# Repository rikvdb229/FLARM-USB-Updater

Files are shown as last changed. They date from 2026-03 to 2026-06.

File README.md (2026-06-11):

# FLARM USB Updater — REV B

USB-to-RS232 adapter with 12V boost converter for updating FLARM firmware without external power.

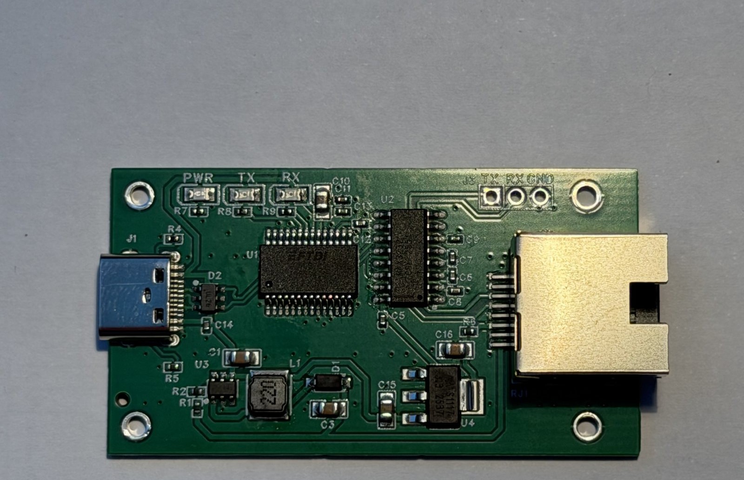
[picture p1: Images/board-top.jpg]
FLARM USB Updater REV B — assembled board


Plug into a PC USB port → connect RJ45 cable to FLARM → run firmware update tool. No 12V bench supply required. Also supports FLARM display firmware updates via the same connector.

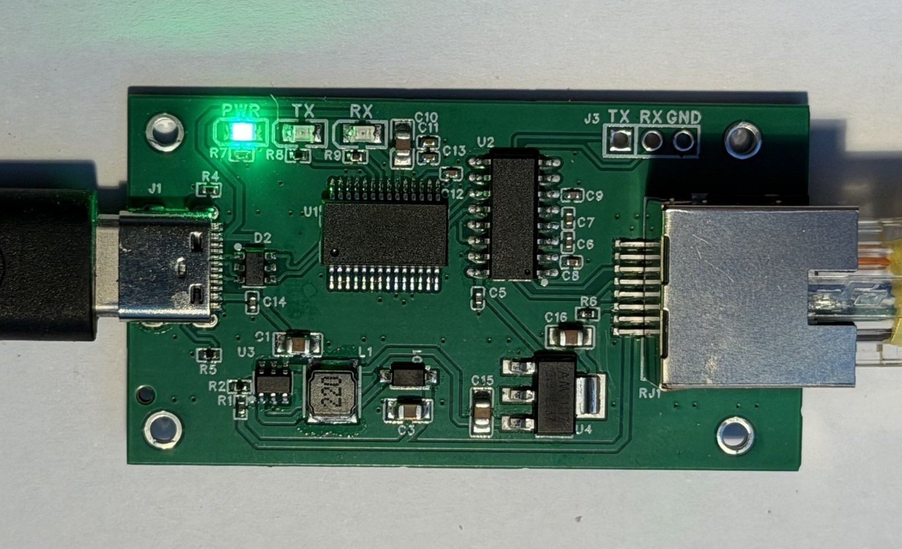
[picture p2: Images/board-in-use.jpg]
In use — USB-C from the PC, RJ45 to the FLARM, green PWR LED lit


> **Tip — connection order:** connect the RJ45 to the FLARM *before* plugging the adapter into the PC. If you hot-plug the FLARM while it's already on USB, the COM port may briefly disconnect and reappear — that's harmless inrush (charging the FLARM's input capacitors through the boost momentarily dips the USB 5 V rail and re-enumerates the FT232), not a fault.

> **Status:** REV B **built and validated** — bench-tested and confirmed updating real FLARM hardware over USB (boost, 12 V rail, and full serial path all verified). Fixes the REV A boost topology bug (12 V rail was dead on all REV A boards). See [Archive/REV_A/](Archive/REV_A/) for the REV A schematic, rework guide, and bring-up log.

> **Disclaimer:** This is an unofficial, community-built project. It is **not affiliated with, authorized, sponsored, or endorsed by FLARM Technology Ltd.** "FLARM" and "PowerFLARM" are trademarks of FLARM Technology Ltd.; they are used here only to describe device compatibility. Firmware updates are performed using FLARM's own official update tool — this project supplies power and a serial connection only. Use at your own risk; you are responsible for any device you connect it to.

> 🛒 **Want one ready-made?** Pre-built, tested boards for fellow pilots — **~€40, shipping excluded** (cost-share to fund the next batch). Start a [Discussion](../../discussions) or email [flarm@rvdb.dev](mailto:flarm@rvdb.dev).

## Features

- Powered entirely from USB (5V)
- 5V → ~12V boost converter (MT3608) supplies FLARM via RJ45 pins 1 & 2
- FT232RL USB-to-UART bridge — uses Microsoft built-in usbser.sys, no driver install on Win10/11
- MAX3232 RS232 level shifter, powered from the 3.3V rail (±5V signaling, RS232-compliant with all FLARM RS232 ports)
- B5819W Schottky boost freewheel diode — also provides backfeed protection into live 12V aircraft bus
- USB ESD protection (USBLC6-2SC6) on D+/D−
- USB-C connector with proper CC pull-downs
- Power, TX and RX LED indicators
- Dedicated AMS1117-3.3 LDO — 3.3V supply for FLARM accessories (RJ45 pin 3), up to 800mA
- R6 (10Ω) isolates AMS1117 output from FLARM's internal 3.3V on pin 3

## Hardware

Designed in **EasyEDA Pro** for direct JLCPCB SMT assembly ordering.

**PCB REV B:** 53.4 × 30.5 mm (2102 × 1200 mil), 2-layer FR4, 1oz copper. Single-sided top routing with a solid bottom GND plane, 54 stitching vias.

> **Note on C-numbers:** IC and connector C-numbers are confirmed. Passive C-numbers
> (resistors/caps) are from the JLCPCB Basic parts library and should be verified in
> EasyEDA before ordering — search the value + package if a number doesn't match.

### Component List (REV B)

| Ref  | Description | JLCPCB # | Class |
| ---- | --- | --- | --- |
| U1 | FT232RL USB-UART SSOP-28 | C8690 | Extended |
| U2 | MAX3232CSE+T RS232 transceiver SOIC-16 | C7258 | Extended |
| U3 | MT3608 boost converter SOT-23-6 | C84817 | Extended |
| U4 | AMS1117-3.3 LDO regulator SOT-223 | C6186 | Basic |
| L1 | 22µH shielded inductor 1A (SMNR4020) | C135264  | Extended |
| D1 | B5819W SL Schottky 40V/1A SOD-123 | C8598 | Basic |
| D2 | USBLC6-2SC6 USB ESD clamp SOT-23-6 | C7519 | Extended |
| J1 | USB-C receptacle TYPE-C-31-M-12 | C165948  | Extended |
| RJ1  | RJ45 SMD 8P8C (RJ-064-1) | C7205199 | Extended |
| J3 | 1×3 PTH header 2.54mm (unpopulated) | — | — |
| LED1 | Green LED 0805 — power (KT-0805G) | C2297 | Basic |
| LED2 | Yellow LED 0805 — TX (KT-0805Y) | C2296 | Basic |
| LED3 | Yellow LED 0805 — RX (KT-0805Y) | C2296 | Basic |
| R1 | 100kΩ 0402 — MT3608 FB top | C25741 | Basic |
| R2 | 5.1kΩ 0402 — MT3608 FB bottom | C25905 | Basic |
| R4 | 5.1kΩ 0402 — USB-C CC1 | C25905 | Basic |
| R5 | 5.1kΩ 0402 — USB-C CC2 | C25905 | Basic |
| R6 | 10Ω 0402 — RJ45 pin 3 isolation | C25077 | Basic |
| R7 | 680Ω 0402 — power LED | C25130 | Basic |
| R8 | 680Ω 0402 — TX LED | C25130 | Basic |
| R9 | 680Ω 0402 — RX LED | C25130 | Basic |
| C1 | 22µF / 25V 0805 — MT3608 Vin | C45783 | Basic |
| C3 | 22µF / 25V 0805 — MT3608 Vout | C45783 | Basic |
| C5 | 100nF 0402 — MAX3232 VCC bypass (3.3V rail)| C307331  | Basic |
| C6 | 100nF 0402 — MAX3232 C1+/C1− (charge pump) | C307331  | Basic |
| C7 | 100nF 0402 — MAX3232 C2+/C2− (charge pump) | C307331  | Basic |
| C8 | 100nF 0402 — MAX3232 V+ storage | C307331  | Basic |
| C9 | 100nF 0402 — MAX3232 V− storage | C307331  | Basic |
| C10  | 4.7µF / 25V 0805 — FT232RL VCC bulk | C1779 | Basic |
| C11  | 100nF 0402 — FT232RL VCC | C307331  | Basic |
| C12  | 100nF 0402 — FT232RL VCCIO | C307331  | Basic |
| C13  | 100nF 0402 — FT232RL VCC | C307331  | Basic |
| C14  | 100nF 0402 — USBLC6 VCC | C307331  | Basic |
| C15  | 22µF / 25V 0805 — AMS1117 Vin | C45783 | Basic |
| C16  | 22µF / 25V 0805 — AMS1117 Vout | C45783 | Basic |

**35 components (34 SMT + 1 PTH unpopulated) — 7 Extended parts ($21 JLCPCB setup fees)**

### Net Names

| Net | Description | Trace class |
| --- | --- | --- |
| VUSB | USB 5V power rail | Power (≥20mil) |
| GND | Ground (pour both layers) | pour |
| SW | MT3608 switching node (L1 → U3 SW → D1 anode) | default |
| V12_OUT | After Schottky D1 (~12.0V) to RJ45 pins 1,2 | Power_12V (≥15mil) |
| V3V3 | AMS1117-3.3 output | default |
| V3V3_OUT | After R6 to RJ45 pin 3 | default |
| FT_3V3 | FT232RL 3V3OUT (pin 17, decoupling only) | default |
| UART_TX | FT232RL TXD → MAX3232 T1IN → J3 | default |
| UART_RX | MAX3232 R1OUT → FT232RL RXD, also J3 | default |
| RS232_TX | MAX3232 T1OUT → RJ45 pin 6 | default |
| RS232_RX | RJ45 pin 5 → MAX3232 R1IN | default |
| UD+, UD− | USB data, FT232 side (diff pair DP1) | 6/6 mil |
| UD_IN+, UD_IN− | USB data, USB-C side (diff pair DP2) | 6/6 mil |
| CC1, CC2 | USB-C configuration channel | default |
| TXLED, RXLED | FT232RL CBUS0/CBUS1 (active-low) to LEDs | default |
| FB | MT3608 feedback node | default |
| CP1P, CP1N, CP2P, CP2N | MAX3232 charge pump | default |
| VS_POS, VS_NEG | MAX3232 V+/V− supply | default |
| LED1_K, LED2_K, LED3_K | LED cathode nodes | default |

### FLARM RJ45 Pinout (8P8C)

| Pin | Signal | This device |
| --- | --- | --- |
| 1, 2 | +12V | From boost via D1 (~12.0V) |
| 3 | FLARM 3V3 | From AMS1117-3.3 (U4) via R6 (10Ω) |
| 4, 7, 8 | GND | PCB GND |
| 5 | FLARM TX  | RS232 RX input (MAX3232 R1IN) |
| 6 | FLARM RX  | RS232 TX output (MAX3232 T1OUT) |
| 9, 10 | Shield | PCB GND copper pour |

The pinout is silkscreened on the back of the board:

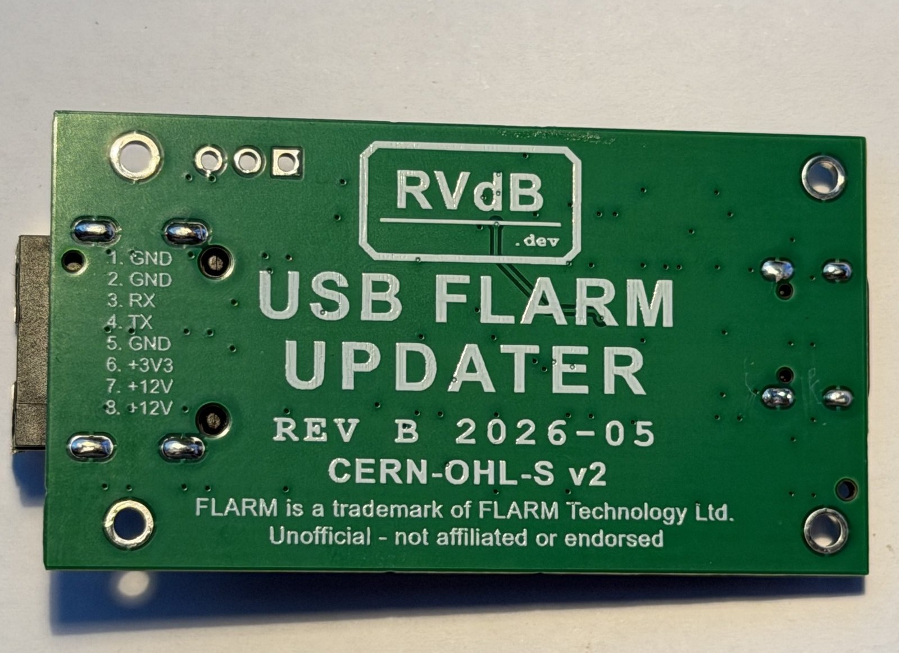
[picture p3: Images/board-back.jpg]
Board back — silkscreen pinout legend, branding, and CERN-OHL-S licence


> **SMD RJ45 note:** The RJ-064-1 connector uses reversed pad numbering (pad 1 = RJ45 pin 8). The PCB routing compensates for this — the netlist pad references and the RJ45 pin numbers in this table are intentionally different.

**Pin 3 design note:** FLARM outputs 3.3V on pin 3 (up to 200mA per FLARM manual) to power external accessories. The AMS1117-3.3 on this board also outputs 3.3V on pin 3. R6 (10Ω) isolates the two 3.3V sources:

- **FLARM update:** Both regulators output ~3.3V. R6 limits mismatch current to ~10mA max. AMS1117 handles this safely (no protection diode needed with small output caps).
- **Display update:** Display draws power from AMS1117 through R6. At 20mA → 0.2V drop (3.1V), at 50mA → 0.5V drop (2.8V). Most displays work fine at 3.0V+.
- **R6 can be replaced with 0Ω** if display voltage drop is an issue and FLARM backfeed isolation is not needed.

**Display updates — TX/RX crossover cable:** For display firmware updates, TX and RX
are swapped relative to FLARM updates. Use a crossover RJ45 cable (pins 5 and 6 swapped)
labeled "DISPLAY". RS232 is non-damaging if crossed — receivers are high-impedance.

### Breakout Header (unpopulated)

**J3 — TTL UART (1×3, 2.54mm)**

Exposes the TTL-level UART signals between the FT232RL and MAX3232. Not assembled by JLCPCB — solder a pin header when needed.

| Pin | Signal | Description |
| --- | --- | --- |
| 1 | TX | 3.3V TTL TX from FT232RL |
| 2 | RX | 3.3V TTL RX to FT232RL |
| 3 | GND | Signal reference |

> **VCCIO note:** The FT232RL VCCIO (pin 4) is tied to 3V3OUT (the FT232RL's internal 3.3V regulator), so J3 outputs **3.3V TTL** and is safe to connect directly to 3.3V MCUs (nRF, RP2040, ESP32, STM32, etc.). FT232RL VCC (pin 20) remains on USB 5V — that powers the USB interface and does not affect the I/O logic level. The MAX3232 is also powered from the 3.3V rail, so the FT232RL↔MAX3232 interface is level-matched on both directions with in-spec margin.

### LED Indicators

| LED  | Colour | Signal | Resistor | Current | Behaviour |
| ---- | --- | --- | --- | --- | --- |
| LED1 | Green (C2297)  | VUSB → R7 → GND | 680Ω | 3.2mA | Always on when USB connected |
| LED2 | Yellow (C2296) | VUSB → R8 → TXLED# | 680Ω | 4.3mA | Flashes during TX |
| LED3 | Yellow (C2296) | VUSB → R9 → RXLED# | 680Ω | 4.3mA | Flashes during RX |

TXLED# and RXLED# are active-low, default CBUS0/CBUS1 factory config — no EEPROM needed.

## What Else Can It Do?

With the FLARM cable connected, this board provides full RS232 + power — not just firmware updates:

- **IGC flight log download** — open FLARM Tool, download flight logs for OLC/competition submission.
- **FLARM configuration** — change aircraft type, competition ID, NMEA output sentences, baud rate, and other settings via the serial link.
- **Live NMEA diagnostics** — open a serial terminal (PuTTY, Tera Term) at 19200 baud to watch GPS, traffic, and error sentences in real-time.
- **General-purpose RS232 adapter** — make an RJ45 cable with only GND (pins 4/7/8), TX (pin 5), and RX (pin 6) connected. Leave pins 1/2 (12V) and 3 (3.3V) unconnected. The boost converter idles at ~1mA with no load.

## Cable Configurations

| Cable | Wiring | Use |
| --- | --- | --- |
| **FLARM** (straight) | All pins 1:1 | Firmware update, config, IGC download, diagnostics |
| **DISPLAY** (crossover) | Pins 5 ↔ 6 swapped | Display firmware update |
| **RS232 only** | Pins 4, 5, 6, 7, 8 only | General RS232 (no 12V/3.3V) |

## FT232RL EEPROM Customization (optional)

Use FTDI's free **FT_PROG** tool (Windows) to program the FT232RL's internal EEPROM:

- **Device description**: set to "FLARM USB Updater" — shows in Device Manager instead of generic "USB Serial Converter"
- **Serial number**: unique per board — helps identify the right COM port when multiple FTDI devices are connected

One-time USB programming step per board. Not required for basic operation.

## Boost Converter

Standard boost topology (fixed in REV B):

```
VUSB ── L1(22µH) ── SW ── D1 ── V12_OUT ── RJ45 pins 1,2
                    │
                   U3 SW pin
```

Vout = 0.6 × (1 + R1/R2) = 0.6 × (1 + 100k/5.1k) ≈ **12.35V**
After B5819W drop (~0.35V): ≈ **12.0V** at RJ45 — within FLARM 8–36V input range.

| Parameter | Value |
| --- | --- |
| Output voltage | 12.35V (12.0V after diode) |
| Duty cycle | ~60% |
| Inductor ripple | 113mA peak-to-peak |
| Peak inductor current | 304mA (vs 1A L1 rating) |
| Output ripple | <1mV estimated |
| Output cap | C3 = 22µF at 25V (2× voltage margin) |

## Power Budget

| Consumer | Current (mA) |
| --- | --- |
| FT232RL | 15 |
| MAX3232 | 5 |
| USBLC6 | 0.5 |
| AMS1117 quiescent | 5 |
| LED1 (power) | 3.2 |
| LED2 (TX, avg) | 2.2 |
| LED3 (RX, avg) | 2.2 |
| MT3608 boost @ 85mA load | 247 |
| **Total USB draw** | **~280mA** |

USB 2.0 limit: 500mA → 56% used. A **regular FLARM runs on any standard USB port** (bench-tested with a Flarm06).

A **PowerFLARM** draws more (~165mA @ 12V → ~510mA on USB) — fine on USB 3.0 / USB-C ports, which supply well above 500mA. On an older 500mA USB 2.0 port that's right at the limit, so if it doesn't power up, use a USB-C charger (1.5A+).

## Cost Estimate (JLCPCB SMT assembly)

| Qty | PCB | SMT | Extended fees | Components | Shipping | Total | Per board |
| --- | --- | --- | --- | --- | --- | --- | --- |
| 5 | $2  | $8  | $21 | ~$37.50 | ~$15 | ~$83.50 | ~$16.70 |
| 10  | $4  | $8  | $21 | ~$75 | ~$15 | ~$123 | ~$12.30 |

## Changes from REV A

REV A was ordered, received, and bench-tested. RS232, USB, 3.3V rail, and LEDs all worked. The 12V rail produced 0V on every board due to incorrect boost topology. Rework instructions are preserved in [Archive/REV_A/REV_A_Rework_Guide.md](Archive/REV_A/REV_A_Rework_Guide.md).

**Fixed in REV B:**

1. **Boost topology** — L1 moved from SW↔output to VUSB↔SW. D1 moved from output↔V12_OUT to SW↔V12_OUT. Now a standard boost.
2. **Removed R3** (10kΩ EN pull-up) — EN tied directly to VUSB.
3. **Removed C2** (100nF boost input HF) — not required by MT3608 datasheet.
4. **Removed C4** (4.7µF boost output aux) — not required by MT3608 datasheet.
5. **VBOOST net eliminated** — SW→D1→V12_OUT is one path.
6. **LED2 colour** — corrected from green to yellow (KT-0805Y / C2296) to match physical BOM.
7. **MAX3232 supply** — VCC (U2 pin 16) and its bypass cap C5 moved from VUSB (5V) to the 3.3V rail (AMS1117 V3V3, regulator side of R6). At VCC=3.3V the MAX3232 driver input threshold is 2.0V, which the FT232RL TXD (2.2V min at VCCIO=3.3V) meets in spec; previously the 5V-powered MAX3232 needed 2.4V and was out of spec worst-case. Both ICs now share the 3.3V rail (level-matched). J3 is therefore 3.3V TTL — safe for any 3.3V MCU.

## Design Verification (REV B)

Netlist + BOM review, re-verified 2026-05-15 against the REV B EasyEDA project export (programmatic netlist parse against component datasheets):

- FT232RL: all 28 pins verified (TEST→GND, CTS/DSR/DCD/RI→GND, OSCI/OSCO NC, VCC on VUSB=5V, VCCIO on FT_3V3=3.3V)
- MAX3232: VCC on V3V3 (3.3V rail); C5 VCC bypass; C6/C7 charge pump flying caps; C8/C9 V+/V− storage. Ch1 UART↔RS232. T2IN (pin 10) tied to GND.
- MT3608: VUSB→L1→SW→D1→V12_OUT. Feedback 100k/5.1k → 12.35V. **Boost topology correct (REV A bug fixed).**
- USB-C: CC1/CC2 pulldowns 5.1kΩ, D+/D− through USBLC6, diff-pair rule active (DP1, DP2, 6/6 mil), both orientations
- AMS1117-3.3: V3V3 → R6 (10Ω) → RJ45 pin 3, adequate headroom
- LED circuits: active-low CBUS, correct polarity, 3.2–4.3mA current
- RJ45 pinout: matches FLARM IGC specification (accounting for SMD connector pad reversal)
- GND copper pour on both layers, 54 stitching vias
- Power budget: ~280mA within USB 2.0 500mA limit
- All capacitor voltage ratings: ≥1.8×, all resistor power ratings: <40%

## Bring-up Checklist (before connecting to FLARM)

1. Visual inspection: USB-C orientation, RJ45 jack seating, no tombstoned 0402s
2. USB plug-in: LED1 (green) on. Host enumerates as FTDI serial device.
3. DMM: 5V on VUSB test points, 3.3V on V3V3, **12.0V on V12_OUT (RJ45 pins 1,2)**
4. Loopback test via `flarm_query.py` or `flarm_monitor.py` — TX/RX LEDs flash
5. Connect FLARM on bench supply first (not live 12V aircraft bus) for initial test

## Files

- [EDA/USB_FLARM_UPDATER.eprj](EDA/USB_FLARM_UPDATER.eprj) — EasyEDA Pro project (REV B)
- [EDA/ProPrj_USB_FLARM_UPDATER_2026-05-29.epro](EDA/ProPrj_USB_FLARM_UPDATER_2026-05-29.epro) — REV B as-built source export (the fabbed design)
- [EDA/Gerber_PCB1_2026-05-27.zip](EDA/Gerber_PCB1_2026-05-27.zip) — REV B Gerber for JLCPCB
- [EDA/BOM_Board1_PCB1_2026-05-27.csv](EDA/BOM_Board1_PCB1_2026-05-27.csv) — REV B BOM
- [EDA/PickAndPlace_PCB1_2026-05-27.xlsx](EDA/PickAndPlace_PCB1_2026-05-27.xlsx) — REV B SMT pick-and-place
- [EDA/Netlist_Schematic1_2026-05-27.tel](EDA/Netlist_Schematic1_2026-05-27.tel) — REV B netlist (for parser audit)
- [EDA/silkscreen_back_REV_B.svg](EDA/silkscreen_back_REV_B.svg) — back silkscreen artwork
- [EDA/USB_FLARM_UPDATER_backup/](EDA/USB_FLARM_UPDATER_backup/) — dated project snapshots
- [EDA/3DPCB.step](EDA/3DPCB.step) — board 3D model (STEP) for enclosure / mechanical design
- [Images/](Images/) — board photos used in this README
- [Docs/FLARM_USB_Updater_Design_Document.docx](Docs/FLARM_USB_Updater_Design_Document.docx) — design document (BOM, pinout, power budget, bring-up)
- Component datasheets — see each part's LCSC code (C-number) in the [BOM](EDA/BOM_Board1_PCB1_2026-05-27.csv); enter it at lcsc.com for the datasheet
- [Enclosure/](Enclosure/) — 3D-printable case: `box` + `lid` (STEP/3MF/STL) and `enclosure-assembly.step` (board-in-box fit reference)
- [Archive/REV_A/](Archive/REV_A/) — REV A schematic, PCB, BOM, Gerber, rework guide, bring-up log
- [flarm_query.py](flarm_query.py) — query a connected FLARM (version / device info); [flarm_monitor.py](flarm_monitor.py) — log the serial NMEA stream
- [LICENSE](LICENSE) — CERN-OHL-S v2 licence text

## Support the project

This is fully open hardware — anyone can build the board from the Gerbers in [EDA/](EDA/) and the BOM. If the design or documentation saved you time, or you'd like to back continued development:

- ☕ **[Buy Me a Coffee](https://buymeacoffee.com/rikvdb)** — one-time thanks, any amount
- 🛒 **Pre-built, tested boards** (~€40, shipping excluded) — see the note at the top, or reach out via [Discussions](../../discussions) / [flarm@rvdb.dev](mailto:flarm@rvdb.dev)

Buying a board doesn't get you anything the open files don't — you're paying for assembly, testing, and the time saved. The repo is the canonical source either way.

## Questions & Contact

- 🐛 **Bug or technical problem** → [open an issue](../../issues/new)
- 💬 **Question, build help, or interested in a board** → [GitHub Discussions](../../discussions)
- ✉️ **Private / direct** → [flarm@rvdb.dev](mailto:flarm@rvdb.dev)

## License

Copyright Rik Vanden Boer.

This source describes Open Hardware and is licensed under the **CERN-OHL-S v2** (CERN Open Hardware Licence Version 2 — Strongly Reciprocal). You may redistribute and modify this source and make products using it under the terms of CERN-OHL-S v2 ([LICENSE](LICENSE)).

This source is distributed WITHOUT ANY EXPRESS OR IMPLIED WARRANTY, INCLUDING OF MERCHANTABILITY, SATISFACTORY QUALITY AND FITNESS FOR A PARTICULAR PURPOSE. Please see the licence for the full text.

As a strongly reciprocal licence: if you make and distribute a (modified) board based on this design, you must make the complete source (schematics, PCB, BOM) available under the same licence.

"FLARM" and "PowerFLARM" are trademarks of FLARM Technology Ltd. and are **not** covered by this licence — see the disclaimer at the top of this document.

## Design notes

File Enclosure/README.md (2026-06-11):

# Enclosure

3D-printable case for the FLARM USB Updater (REV B).

## Files
Each part comes as `.step`/`.3mf` (editable source — open in FreeCAD, Fusion 360, etc.) and `.stl` (print-ready mesh).
- **`box.*`** — the case body.
- **`lid.*`** — **plain lid** (no markings). The default for builders.
- **`lid_branded.*`** — same lid with the **RVdB.dev / USB FLARM UPDATER** logo embossed on top. Print this if you want the branded look, or `lid.*` for a clean one.
- **`enclosure-assembly.step`** — board-in-box fit **reference only, do not
  print**. Shows how the REV B PCB sits inside the case (USB-C and RJ45 cutout
  alignment); use it if you respin the board or modify the case.

Both lids share the same outer geometry and fit the same box — they differ only in the top-face emboss.

> Slicers Bambu Studio / OrcaSlicer / PrusaSlicer also import the `.step`/`.3mf`
> directly, so you usually don't need the STL.

## Printing
- **Material:** PLA is fine for normal bench/hangar use — the board barely makes
  heat (~2.5 W max off USB). **Use PETG or ASA if a unit might be left in a hot
  cockpit or car** (PLA softens ~50–60 °C; a sun-baked cockpit exceeds that).
- **Suggested settings:** ~0.2 mm layers, 3 perimeters, 15–20 % infill. No
  supports needed if the connector openings face up; otherwise minimal supports
  at the USB-C / RJ45 cutouts.

## Fit
Designed around the REV B PCB outline with openings for the **USB-C (J1)** and
**RJ45 (RJ1)** connectors and a window for the LEDs. If you respin the board,
re-check the cutout positions against the new layout before printing.

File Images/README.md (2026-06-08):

# Images

Photos and screenshots used in the main README and for sharing the project.

Suggested files (drop them here with these names so README links stay stable):

| File | What | Use |
|---|---|---|
| `board-top.jpg` | assembled board, top-down, clean background | README hero shot + GitHub social preview |
| `board-in-use.jpg` | plugged into a laptop USB-C with RJ45 to a FLARM | shows the value prop ("no bench supply") |
| `board-back.jpg` | back silkscreen artwork (logo / licence / trademark) | shows the custom branding |
| `terminal-update.png` | serial terminal / FLARM update succeeding | proof of function (optional) |
| `enclosure.jpg` | the 3D-printed case (with board inside) | add after the print is done |

**Formats:** JPG for photos (smaller), PNG for screenshots. Keep each under
~1–2 MB so the repo stays lightweight.

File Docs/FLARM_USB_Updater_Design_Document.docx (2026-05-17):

# FLARM USB Updater

Hardware Design Document

REV B

PCB: 53.4 × 30.5 mm (2102 × 1200 mil), 2-layer FR4

April 2026

# 1. Overview

The FLARM USB Updater is a USB-to-RS232 adapter with an integrated 12V boost converter, designed to update FLARM firmware and FLARM displays without requiring external power. It connects to a PC via USB-C and to the FLARM unit via an RJ45 cable following the IGC specification.

## 1.1 Key Features

- USB-C powered — no external 12V supply needed
- FT232RL USB-UART bridge (uses built-in Windows usbser.sys driver)
- MAX3232 RS232 level converter for FLARM communication
- MT3608 boost converter: 5V USB → 12V FLARM power
- AMS1117-3.3 LDO for FLARM 3.3V pin
- USBLC6-2SC6 ESD protection on USB data lines
- 3 status LEDs: power (green), TX (green), RX (yellow)
- TTL UART breakout header (J3) for direct TTL access
- All SMT, JLCPCB assembly compatible

## 1.2 Use Cases

1. FLARM firmware updates (straight RJ45 cable)
2. FLARM display updates (crossover RJ45 cable, pins 5+6 swapped)
3. IGC flight log download
4. FLARM configuration and live NMEA diagnostics
5. General-purpose USB to RS232 adapter (cable with GND/TX/RX only)

# 2. System Architecture

The design consists of five functional blocks:

## 2.1 Power Supply

Boost Converter (MT3608): Standard boost topology. L1 (22µH) sits between VUSB and SW node. MT3608 internal FET switches SW to GND; Schottky D1 (B5819W) conducts when FET opens, storing L1's magnetic energy into C3. Feedback divider R1 (100kΩ) / R2 (5.1kΩ) sets Vout = 0.6 × (1 + R1/R2) ≈ 12.35V, yielding ~12.0V at RJ45 after the ~0.35V D1 drop. 22µH is the top of the MT3608 recommended range, chosen for lower peak current and output ripple at the ~85mA FLARM load.

LDO (AMS1117-3.3): Provides 3.3V from USB 5V for FLARM pin 3. R6 (10Ω) limits current between the LDO output and FLARM's internal 3.3V regulator to prevent backfeed.

Power Budget: Classic FLARM draws ~85mA at 12V. Total USB current: ~280mA, well within any USB port's capability.

## 2.2 USB Interface

USB-C connector (J1) with CC1/CC2 pull-down resistors (R4, R5: 5.1kΩ) for UFP sink identification. USBLC6-2SC6 (D2) provides ESD protection on D+/D- lines. Both USB-C orientations are supported.

## 2.3 USB-UART Bridge

FT232RL (U1) converts USB to TTL UART. Chosen over CH340C because the November 2024 Windows Update broke CH340 drivers; FT232RL uses the built-in usbser.sys driver. CBUS0 (TXLED#) and CBUS1 (RXLED#) drive status LEDs via active-low outputs. Pin 26 (TEST) tied to GND. Unused modem control inputs (RI#, DSR#, DCD#, CTS#) tied to GND.

## 2.4 RS232 Level Converter

MAX3232 (U2) converts TTL UART to RS232 levels. U2 is powered from the 3.3V rail (V3V3, AMS1117 output on the regulator side of R6), so the FT232RL↔MAX3232 interface is level-matched at 3.3V in both directions with in-spec margin (MAX3232 driver V_IH = 2.0V at VCC = 3.3V; FT232RL TXD high = 2.2V min at VCCIO = 3.3V). C5 is VCC bypass (pin 16). C6/C7 are the charge pump flying caps (C1±/C2±). C8/C9 are V+/V- storage caps. All five are 100nF, which is the MAX3232 datasheet value for 3V–5.5V operation. Channel 1 carries FLARM communication. Channel 2 is unused; T2IN (pin 10) is tied to GND to prevent floating-input oscillation; the other channel-2 pins are left floating (allowed by datasheet).

## 2.5 LED Indicators

All LEDs use the same topology: VUSB → LED anode (pin 1) → LED cathode (pin 2) → R → sink.

- LED1 (green, KT-0805G): Power indicator. R7 (680Ω) to GND. Always on. I = (5-2.8)/680 = 3.2mA.
- LED2 (yellow, KT-0805Y): TX activity. R8 (680Ω) to TXLED (CBUS0). I = (5-2.1)/680 = 4.3mA when active.
- LED3 (yellow, KT-0805Y): RX activity. R9 (680Ω) to RXLED (CBUS1). I = (5-2.1)/680 = 4.3mA when active.

# 3. RJ45 Pinout (IGC Specification)

Pin numbering follows the IGC GNSS FR specification. The SMD RJ45 connector (RJ-064-1) has reversed pad numbering (pad 1 = RJ45 pin 8), accounted for in the PCB routing.

Pin | Signal | Notes
1 | +12V (V12_OUT) | Linked with pin 2
2 | +12V (V12_OUT) | Linked with pin 1
3 | +3.3V (V3V3_OUT via R6) | FLARM supplies 3V during updates
4 | GND | Linked with pins 7, 8
5 | FLARM TX (RS232_RX) | PC-side: SUB-D9 pin 2
6 | FLARM RX (RS232_TX) | PC-side: SUB-D9 pin 3
7 | GND | Linked with pins 4, 8
8 | GND | PC-side: SUB-D9 pin 5

# 4. Net Names

Net Name | Description
VUSB | USB 5V supply from USB-C
GND | Ground (pour both layers)
SW | Boost switch node (L1 → U3 SW → D1 anode)
V12_OUT | Boost output after Schottky D1 (~12.0V)
FB | Boost feedback divider midpoint (0.6V ref)
V3V3 | AMS1117 3.3V output
V3V3_OUT | 3.3V to FLARM via R6 (10Ω)
FT_3V3 | FT232RL 3V3OUT (pin 17, C12 decoupling only)
UD+ | USB data positive (differential pair, post-ESD)
UD- | USB data negative (differential pair, post-ESD)
UD_IN+ | USB data positive (USB-C side of USBLC6)
UD_IN- | USB data negative (USB-C side of USBLC6)
CC1 | USB-C configuration channel 1 (5.1kΩ to GND)
CC2 | USB-C configuration channel 2 (5.1kΩ to GND)
UART_TX | TTL-level TX (FT232RL → MAX3232 / J3)
UART_RX | TTL-level RX (MAX3232 / J3 → FT232RL)
RS232_TX | RS232-level TX (to FLARM RX on RJ45)
RS232_RX | RS232-level RX (from FLARM TX on RJ45)
TXLED | FT232RL CBUS0 (active-low TX indicator)
RXLED | FT232RL CBUS1 (active-low RX indicator)
CP1P/CP1N | MAX3232 charge pump 1 flying cap (C6)
CP2P/CP2N | MAX3232 charge pump 2 flying cap (C7)
VS_POS/VS_NEG | MAX3232 ± supply (C8/C9)
LED1_K/LED2_K/LED3_K | LED cathode nodes

# 5. Bill of Materials

34 SMT components + 1 PTH (J3 unpopulated). 7 Extended parts (× $3 = $21 setup fee). REV B removed R3 (EN pull-up — EN tied directly to VUSB), C2 (boost input HF), and C4 (boost output aux) — none required by the MT3608 datasheet.

Estimated cost: 5 boards ≈ $16.70/ea, 10 boards ≈ $12.30/ea

Ref | Part | Description | Package | LCSC | Class
U1 | FT232RL-REEL | USB to UART converter | SSOP-28 | C8690 | Extended
U2 | MAX3232CSE+T | RS232 transceiver (dual) | SOIC-16 | C7258 | Extended
U3 | MT3608 | Step-up DC-DC converter | SOT-23-6 | C84817 | Extended
U4 | AMS1117-3.3 | 3.3V LDO regulator | SOT-223 | C6186 | Basic
D1 | B5819W SL | Schottky diode (boost freewheel) | SOD-123 | C8598 | Basic
D2 | USBLC6-2SC6 | USB ESD protection | SOT-23-6 | C7519 | Extended
L1 | SMNR4020-22UH | 22µH inductor (boost) | 4x4mm SMD | C135264 | Extended
J1 | TYPE-C-31-M-12 | USB-C receptacle | SMD 12-pin | C165948 | Extended
RJ1 | RJ-064-1 | RJ45 jack (SMD) | SMD | C7205199 | Extended
J3 | HDR-M 1x3P | TTL UART breakout (unpop.) | 2.54mm PTH | N/A | N/A
LED1 | KT-0805G | Power LED (green) | 0805 | C2297 | Basic
LED2 | KT-0805Y | TX LED (yellow) | 0805 | C2296 | Basic
LED3 | KT-0805Y | RX LED (yellow) | 0805 | C2296 | Basic
R1 | 0402WGF1003TCE | 100kΩ ±1% (boost FB top) | 0402 | C25741 | Basic
R2 | 0402WGF5101TCE | 5.1kΩ ±1% (boost FB bottom) | 0402 | C25905 | Basic
R4 | 0402WGF5101TCE | 5.1kΩ ±1% (USB CC1) | 0402 | C25905 | Basic
R5 | 0402WGF5101TCE | 5.1kΩ ±1% (USB CC2) | 0402 | C25905 | Basic
R6 | 0402WGF100JTCE | 10Ω ±1% (LDO to RJ45) | 0402 | C25077 | Basic
R7 | 0402WGF6800TCE | 680Ω ±1% (power LED) | 0402 | C25130 | Basic
R8 | 0402WGF6800TCE | 680Ω ±1% (TX LED) | 0402 | C25130 | Basic
R9 | 0402WGF6800TCE | 680Ω ±1% (RX LED) | 0402 | C25130 | Basic
C1 | CL21A226MAQNNNE | 22µF 25V (boost input) | 0805 | C45783 | Basic
C3 | CL21A226MAQNNNE | 22µF 25V (boost output) | 0805 | C45783 | Basic
C5 | CL05B104KB54PNC | 100nF (MAX3232 VCC decoupling) | 0402 | C307331 | Basic
C6-C9 | CL05B104KB54PNC | 100nF (MAX3232 charge pump + V+/V-) | 0402 | C307331 | Basic
C10 | CL21A475KAQNNNE | 4.7µF (FT232RL VCC bulk) | 0805 | C1779 | Basic
C11-C13 | CL05B104KB54PNC | 100nF (FT232RL VCC/VCCIO decoupling) | 0402 | C307331 | Basic
C14 | CL05B104KB54PNC | 100nF (USBLC6 VCC) | 0402 | C307331 | Basic
C15 | CL21A226MAQNNNE | 22µF 25V (LDO input) | 0805 | C45783 | Basic
C16 | CL21A226MAQNNNE | 22µF 25V (LDO output) | 0805 | C45783 | Basic

# 6. PCB Design

Board: 53.4 × 30.5 mm (2102 × 1200 mil), 2-layer FR4, 1oz copper.

- GND copper pour on both layers; top pour fills gaps between traces, bottom is a solid GND plane
- All signal routing on top layer (single-sided routed) — bottom reserved for uninterrupted GND return
- 54 vias for GND stitching and bottom-plane pad connections
- Net class rules: Power (VUSB) ≥ 20mil, Power_12V (V12_OUT) ≥ 15mil
- USB differential pair (UD+/UD-, UD_IN+/UD_IN-): 6mil/6mil width/space, diff-pair rule active
- Designed in EasyEDA Pro, assembled by JLCPCB

# 7. Key Design Decisions

### FT232RL over CH340C

November 2024 Windows Update broke CH340 drivers. FT232RL uses the built-in usbser.sys driver, eliminating driver issues.

### USBLC6-2SC6 ESD Protection

Aviation and workshop environments have significant ESD risk. The USBLC6-2SC6 protects USB data lines with minimal capacitance impact.

### 22µH Inductor

Top of the MT3608 recommended range (4.7-22µH). Chosen for lower peak inductor current and reduced output ripple at our light load (~85mA at 12V). The SMNR4020-22UH (4x4mm) fits the board.

### R6 Current Limiter (10Ω)

FLARM outputs up to 200mA at 3.3V on pin 3 (per FLARM manual). Without R6, two LDO outputs would fight, causing uncontrolled current flow. R6 limits mismatch current to ~10mA max. AMS1117 handles backfeed safely with 22µF caps (no protection diode needed). Can be replaced with 0Ω if display voltage drop is an issue.

### 680Ω LED Resistors

KT-0805G (green) has a maximum forward current of 5mA. With 680Ω: I = (5-2.8)/680 = 3.2mA, providing comfortable margin. Yellow LEDs run at 4.3mA. Both values produce adequate brightness (430mcd green, 175mcd yellow).

# 8. Changes from REV A

REV A was ordered, received, and bench-tested. RS232, USB, 3.3V rail, and LEDs all worked. The 12V boost rail produced 0V due to incorrect L1/D1 placement. REV B fixes this and refines the MAX3232 supply; there are no deferred electrical issues.

### Fixed in REV B

- Boost topology corrected — L1 now between VUSB and SW (was between SW and output); D1 now between SW and V12_OUT (was between boost output and V12_OUT). Standard textbook boost.
- Removed R3 (10kΩ EN pull-up) — MT3608 EN tied directly to VUSB.
- Removed C2 (100nF boost input HF) — not required by datasheet; C1 (22µF) suffices.
- Removed C4 (4.7µF boost output aux) — not required by datasheet; C3 (22µF) suffices.
- VBOOST net eliminated — SW → D1 → V12_OUT is one continuous output path.
- LED2 colour corrected in documentation: KT-0805Y (yellow), matches physical BOM.
- MAX3232 supply — VCC (U2 pin 16) and bypass cap C5 moved from VUSB (5V) to the 3.3V rail (V3V3, AMS1117 output on the regulator side of R6). Closes a worst-case out-of-spec logic-high margin: a 5V-powered MAX3232 needs 2.4V V_IH but the FT232RL TXD only guarantees 2.2V at VCCIO=3.3V. At VCC=3.3V the MAX3232 V_IH is 2.0V — in spec. Both ICs now share the 3.3V rail.

### FT232RL VCCIO / J3 logic level

FT232RL VCCIO (pin 4) is tied to 3V3OUT (pin 17, the FT232RL's internal 3.3V regulator), so the J3 breakout header is 3.3V TTL — safe to connect directly to any 3.3V MCU (nRF, RP2040, ESP32, STM32). FT232RL VCC (pin 20) is on USB 5V, which powers the USB interface only and does not set the I/O logic level. There are no deferred electrical issues.

# 9. Design Verification (REV B)

Netlist and BOM review, re-verified 2026-05-15 against the REV B EasyEDA project export (programmatic netlist parse cross-checked against component datasheets):

- FT232RL: all 28 pins verified (TEST→GND, CTS/DSR/DCD/RI→GND, OSCI/OSCO NC, VCC on VUSB=5V, VCCIO on FT_3V3=3.3V)
- MAX3232: VCC on V3V3 (3.3V rail); C5 is VCC bypass; C6/C7 charge pumps; C8/C9 V± storage. Ch1 UART↔RS232, T2IN (pin 10) tied to GND
- MT3608: VUSB→L1→SW→D1→V12_OUT. Feedback 100k/5.1k gives 12.35V. Boost topology now correct
- USB-C: CC1/CC2 pulldowns 5.1kΩ, D+/D- through USBLC6 (diff-pair rule active), both orientations
- AMS1117: V3V3 → R6 (10Ω) → RJ45 pin 3, adequate headroom (1.7V)
- LED circuits: active-low CBUS, correct polarity, 3.2–4.3mA (LED2 now correctly yellow)
- RJ45 pinout matches FLARM IGC specification (SMD connector uses reversed pad numbering, compensated in routing)
- USB D+/D- configured as differential pair (DP1, DP2), 6mil/6mil
- GND pour both layers, 54 stitching vias
- Power budget: ~280mA within USB 2.0 500mA limit
- All capacitor voltage ratings ≥1.8×, all resistor power ratings <40%

# 10. Status & Next Steps

1. REV B fabrication files exported (Gerber, BOM, Pick-and-Place) — ready for JLCPCB order
2. Bring-up plan: verify 12V at RJ45 pins 1/2 with DMM before connecting FLARM
3. Validate USB enumeration, TX/RX loopback via monitor_com11.py / poke_flarm.py
4. Program FT232RL EEPROM via FT_PROG (device description, unique serial) — optional

FLARM USB Updater — Design Document

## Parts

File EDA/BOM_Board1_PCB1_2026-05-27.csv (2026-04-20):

No. | Quantity | Comment | Designator | Footprint | Value | Manufacturer Part | Manufacturer | Supplier Part | Supplier
1 | 4 | 22uF | C1,C3,C15,C16 | C0805 | 22uF | CL21A226MAQNNNE | SAMSUNG(三星) | C45783 | LCSC
2 | 9 | 100nF | C5,C6,C7,C8,C9,C11,C12,C13,C14 | C0402 | 100nF | CL05B104KB54PNC | SAMSUNG(三星) | C307331 | LCSC
3 | 1 | 4.7uF | C10 | C0805 | 4.7uF | CL21A475KAQNNNE | SAMSUNG(三星) | C1779 | LCSC
4 | 1 | B5819W SL | D1 | SOD-123_L2.7-W1.6-LS3.7-RD-1 |  | B5819W SL | CJ(江苏长电/长晶) | C8598 | LCSC
5 | 1 | USBLC6-2SC6 | D2 | SOT-23-6_L2.9-W1.6-P0.95-LS2.8-BL |  | USBLC6-2SC6 | ST(意法半导体) | C7519 | LCSC
6 | 1 | TYPE-C-31-M-12 | J1 | USB-C_SMD-TYPE-C-31-M-12_1 |  | TYPE-C-31-M-12 | 韩国韩荣 | C165948 | LCSC
7 | 1 | HDR-M_2.54_1x3P | J3 | HDR-TH_3P-P2.54-V-M
8 | 1 | 22uH | L1 | IND-SMD_L4.0-W4.0_LQH44PN2R2MP0L | 22uH | SMNR4020-22UH | SXN(顺翔诺) | C135264 | LCSC
9 | 1 | KT-0805G | LED1 | LED0805-R-RD |  | KT-0805G | KENTO | C2297 | LCSC
10 | 2 | KT-0805Y | LED2,LED3 | LED0805-R-RD |  | KT-0805Y | KENTO | C2296 | LCSC
11 | 1 | 100kΩ | R1 | R0402 | 100kΩ | 0402WGF1003TCE | UNI-ROYAL(厚声) | C25741 | LCSC
12 | 3 | 5.1kΩ | R2,R4,R5 | R0402 | 5.1kΩ | 0402WGF5101TCE | UNI-ROYAL(厚声) | C25905 | LCSC
13 | 1 | 10Ω | R6 | R0402 | 10Ω | 0402WGF100JTCE | UNI-ROYAL(厚声) | C25077 | LCSC
14 | 3 | 680Ω | R7,R8,R9 | R0402 | 680Ω | 0402WGF6800TCE | UNI-ROYAL(厚声) | C25130 | LCSC
15 | 1 | RJ-064-1 | RJ1 | CONN-SMD_RJ-064 |  | RJ-064-1 | FG(富港) | C7205199 | LCSC
16 | 1 | FT232RL-REEL | U1 | SSOP-28_L10.2-W5.3-P0.65-LS7.8-BL |  | FT232RL-REEL | FTDI(飞特帝亚) | C8690 | LCSC
17 | 1 | MAX3232CSE+T | U2 | SOIC-16_L9.9-W3.9-P1.27-LS6.0-BL |  | MAX3232CSE+T | ADI(亚德诺)/MAXIM(美信) | C7258 | LCSC
18 | 1 | MT3608 | U3 | SOT-23-6_L2.9-W1.6-P0.95-LS2.8-BL |  | MT3608 | 西安航天民芯 | C84817 | LCSC
19 | 1 | AMS1117-3.3 | U4 | SOT-223-3_L6.5-W3.4-P2.30-LS7.0-BR |  | AMS1117-3.3 | AMS | C6186 | LCSC

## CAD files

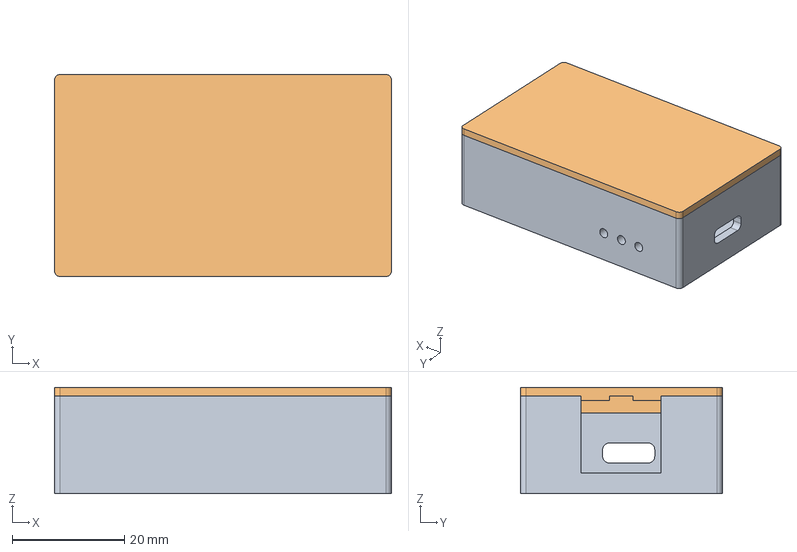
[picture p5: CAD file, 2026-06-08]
Enclosure/enclosure-assembly.step
60.0 x 36.0 x 19.0 mm
Box for PCB

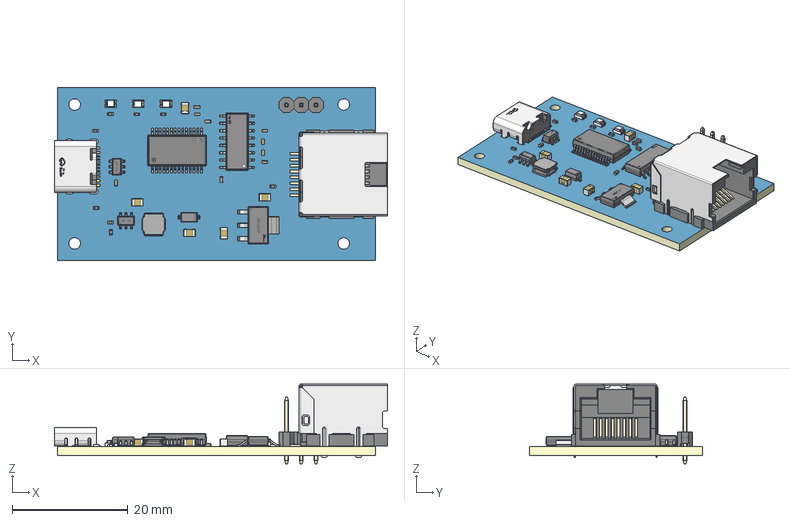
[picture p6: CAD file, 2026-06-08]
EDA/3DPCB.step
57.5 x 30.0 x 13.7 mm
Board~iIuz
TopCopper~iIuz
BottomCopper~iIuz
TopFpcStiffener~iIuz
BottomFpcStiffener~iIuz
C0402~C0402_L1.0-W0.5-H0.5~iIuz x 9
R0402~R0402_L1.0-W0.5-H0.4~iIuz x 8
SSOP-28_L10.2-W5.3-P0.65-LS7.8-BL~SSOP-28_ L10.2-W5.3-H2.0-LS7.8-P0.65~iIuz
LED0805-R-RD~LED0805-RD~iIuz x 3
HDR-TH_3P-P2.54-V-M~HDR-TH_3P-P2.54-M-LI-1X3P~iIuz
SOT-223-3_L6.5-W3.4-P2.30-LS7.0-BR~SOT-223-4P_ L6.5-W3.5-H1.6-LS7.0-P2.30~iIuz
SOT-23-6_L2.9-W1.6-P0.95-LS2.8-BL~SOT-23-6_ L2.9-W1.6-H1.5-LS2.8-P0.95~iIuz x 2
SOIC-16_L9.9-W3.9-P1.27-LS6.0-BL~SOIC-16_ L9.9-W3.9-H1.8-LS6.0-P1.27~iIuz
USB-C_SMD-TYPE-C-31-M-12_1~USB-C_SMD-TYPE-C-31-M-12_1~iIuz
SOD-123_L2.7-W1.6-LS3.7-RD-1~SOD-123_L2.7-W1.6-LS3.7-RD-1~iIuz
IND-SMD_L4.0-W4.0_LQH44PN2R2MP0L~IND-SMD_L4.0-W4.0-H1.65~iIuz
C0805~C0805_L2.0-W1.3-H1.3~iIuz x 5
CONN-SMD_RJ-064~RJ45-SMD_RJ-064~iIuz

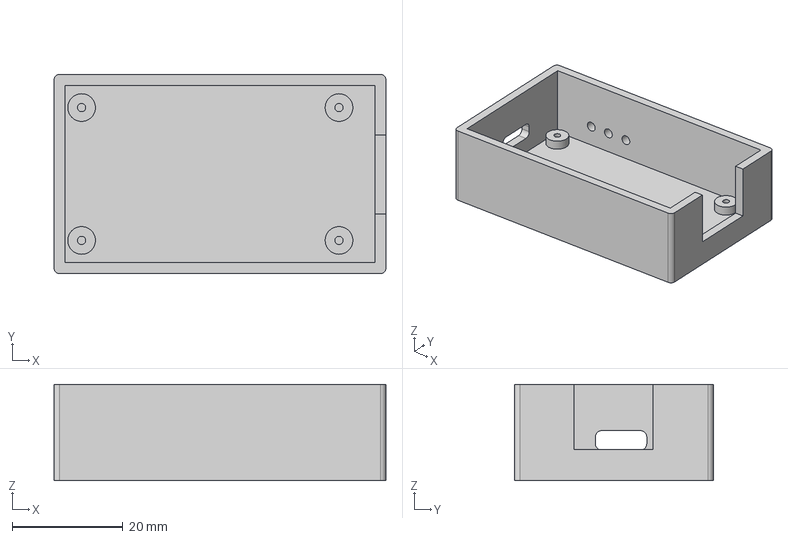
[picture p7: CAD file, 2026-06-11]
Enclosure/box.step
60.0 x 36.0 x 17.4 mm

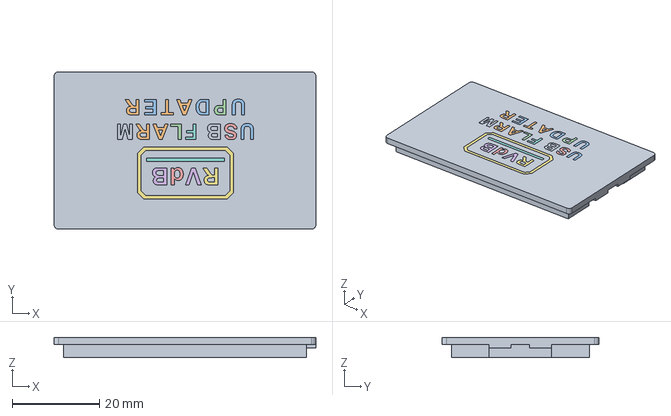
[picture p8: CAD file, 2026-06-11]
Enclosure/lid_branded.step
60.0 x 36.0 x 4.60 mm

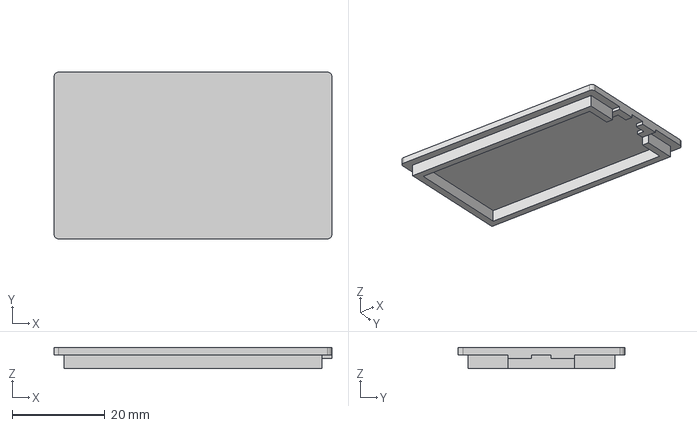
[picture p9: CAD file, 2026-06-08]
Enclosure/lid.step
60.0 x 36.0 x 4.60 mm

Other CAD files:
Enclosure/box.3mf
Enclosure/box.stl
Enclosure/lid.3mf
Enclosure/lid.stl
Enclosure/lid_branded.3mf
Enclosure/lid_branded.stl

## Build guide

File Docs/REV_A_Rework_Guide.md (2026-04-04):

# REV A Rework Guide — Boost Converter Fix

**Board:** FLARM USB Updater REV A
**Issue:** MT3608 boost converter produces 0V — L1 and D1 are in the wrong position
**Fix:** Desolder L1 and D1, resolder with correct topology

## Bug

The inductor (L1) is between SW and VBOOST. It must be between VUSB and SW.
The diode (D1) is between VBOOST and V12_OUT. It must be between SW and VBOOST.

**Before (wrong):**
```
VUSB ── IN    SW ── L1 ── VBOOST ── D1 ── V12_OUT
```

**After (correct):**
```
VUSB ── L1 ── SW ── D1 ── V12_OUT
                             │
                        C3, C4, R1/R2
```

## Tools needed

- Soldering iron with fine tip
- Hot air station (or second iron for D1)
- Flux
- 30 AWG wire or thin enameled wire
- Tweezers
- Kapton tape
- Multimeter
- Solder wick or desoldering braid

## Components involved

| Ref | Part | Package | Notes |
|-----|---|---|---|
| L1 | SMNR4020 22µH | 4.0 x 4.0 mm | Non-polarized, either orientation |
| D1 | B5819W SL | SOD-123 | Anode = unmarked end, Cathode = bar marking |

## Rework steps

### Step 1 — Desolder L1

1. Apply flux around L1 (4x4mm shielded inductor)
2. Heat with hot air at ~350°C or use iron on both pads alternately
3. Lift L1 off with tweezers
4. Clean pads with solder wick
5. Set L1 aside — it will be reused

### Step 2 — Desolder D1

1. Apply flux around D1 (SOD-123, near L1)
2. Heat with hot air or use two irons on both pads simultaneously
3. Lift D1 off with tweezers
4. Clean pads with solder wick
5. Set D1 aside — it will be reused

### Step 3 — Bridge D1's empty pads

Solder a short wire or solder blob across D1's two empty pads. This connects
V12_OUT directly to the VBOOST net (C3, C4, R1 feedback divider), which is the
output of the boost converter.

**Verify with multimeter:** continuity between V12_OUT (RJ45 pins 1&2) and
C3 positive pad.

### Step 4 — Solder L1 with flying wires

1. Cut two pieces of 30 AWG wire, ~15mm each
2. Solder one wire to each pad of L1 (either orientation — inductor is non-polarized)
3. Solder wire A to **VUSB**: use C1 positive pad (22µF cap near MT3608 IN pin)
4. Solder wire B to **MT3608 pin 1 (SW)**: top-left corner pin of U3 (SOT-23-6)

**Verify with multimeter:**
- Continuity from L1 wire A to USB-C VBUS (pin A4/B4)
- Continuity from L1 wire B to MT3608 pin 1 only (no short to other pins)

### Step 5 — Solder D1 with flying wires

1. Cut two pieces of 30 AWG wire, ~15mm each
2. Identify D1 polarity: cathode has a **bar marking** on the package
3. Solder one wire to each end of D1
4. Solder **anode** wire to **MT3608 pin 1 (SW)** — same point as L1 wire B
5. Solder **cathode** wire to **VBOOST/V12_OUT**: use C3 positive pad

**Verify with multimeter (diode mode):**
- Red probe on SW (MT3608 pin 1), black probe on C3 positive → should read ~0.2–0.4V (forward drop)
- Reverse probes → should read OL (open)

### Step 6 — Secure flying components

1. Tack L1 and D1 to the board with a small piece of Kapton tape
2. Ensure no wire-to-wire shorts between L1 and D1 leads
3. Route wires so they don't cross or touch other components

## Pre-power verification checklist

Run these multimeter checks BEFORE plugging in USB:

- [ ] No short between VUSB and GND
- [ ] No short between V12_OUT and GND
- [ ] Continuity: L1 wire A → VUSB rail
- [ ] Continuity: L1 wire B → MT3608 pin 1
- [ ] Continuity: D1 cathode → C3 positive / V12_OUT
- [ ] Continuity: D1 anode → MT3608 pin 1
- [ ] Diode check: SW → V12_OUT reads 0.2–0.4V forward
- [ ] D1 empty pads bridged: V12_OUT → C3 positive continuity
- [ ] No solder bridges on MT3608 (check all 6 pins)

## Power-on test

1. Plug in USB-C cable to a USB port (not a charger)
2. LED1 (green, power) should light up
3. Measure V12_OUT at RJ45 pins 1&2 relative to GND (pins 4/7/8)
4. **Expected: ~12.4V** (no diode drop — feedback regulates the output directly)
5. If voltage is correct, connect to FLARM and test firmware update

## Troubleshooting

| Symptom | Check |
|---|---|
| 0V on V12_OUT | D1 bridged pads? L1 connected to VUSB? |
| ~5V on V12_OUT | D1 reversed (anode/cathode swapped) |
| ~5V and getting hot | Solder bridge on MT3608 pins |
| Unstable / oscillating | Cold solder joint on L1 or D1 wires |
| USB port shuts down | Short between VUSB and GND — check all joints |

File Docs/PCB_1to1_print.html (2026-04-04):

# FLARM USB Updater — REV A — 1 : 1

Board outline at actual size (53.4 x 30.5 mm)

30.5 mm

FLARM USB
Updater
53.4 x 30.5 mm

53.4 mm

Scale check — this bar should measure exactly 100 mm with a ruler:

Each segment = 10 mm. If it doesn't match, adjust your printer to "Actual size" / 100% (not "Fit to page").

To print the full PCB layout at 1:1: Open Docs/PCB.pdf in your PDF viewer and print at 100% / Actual size. Use this page to verify your printer scale is correct with the ruler above.

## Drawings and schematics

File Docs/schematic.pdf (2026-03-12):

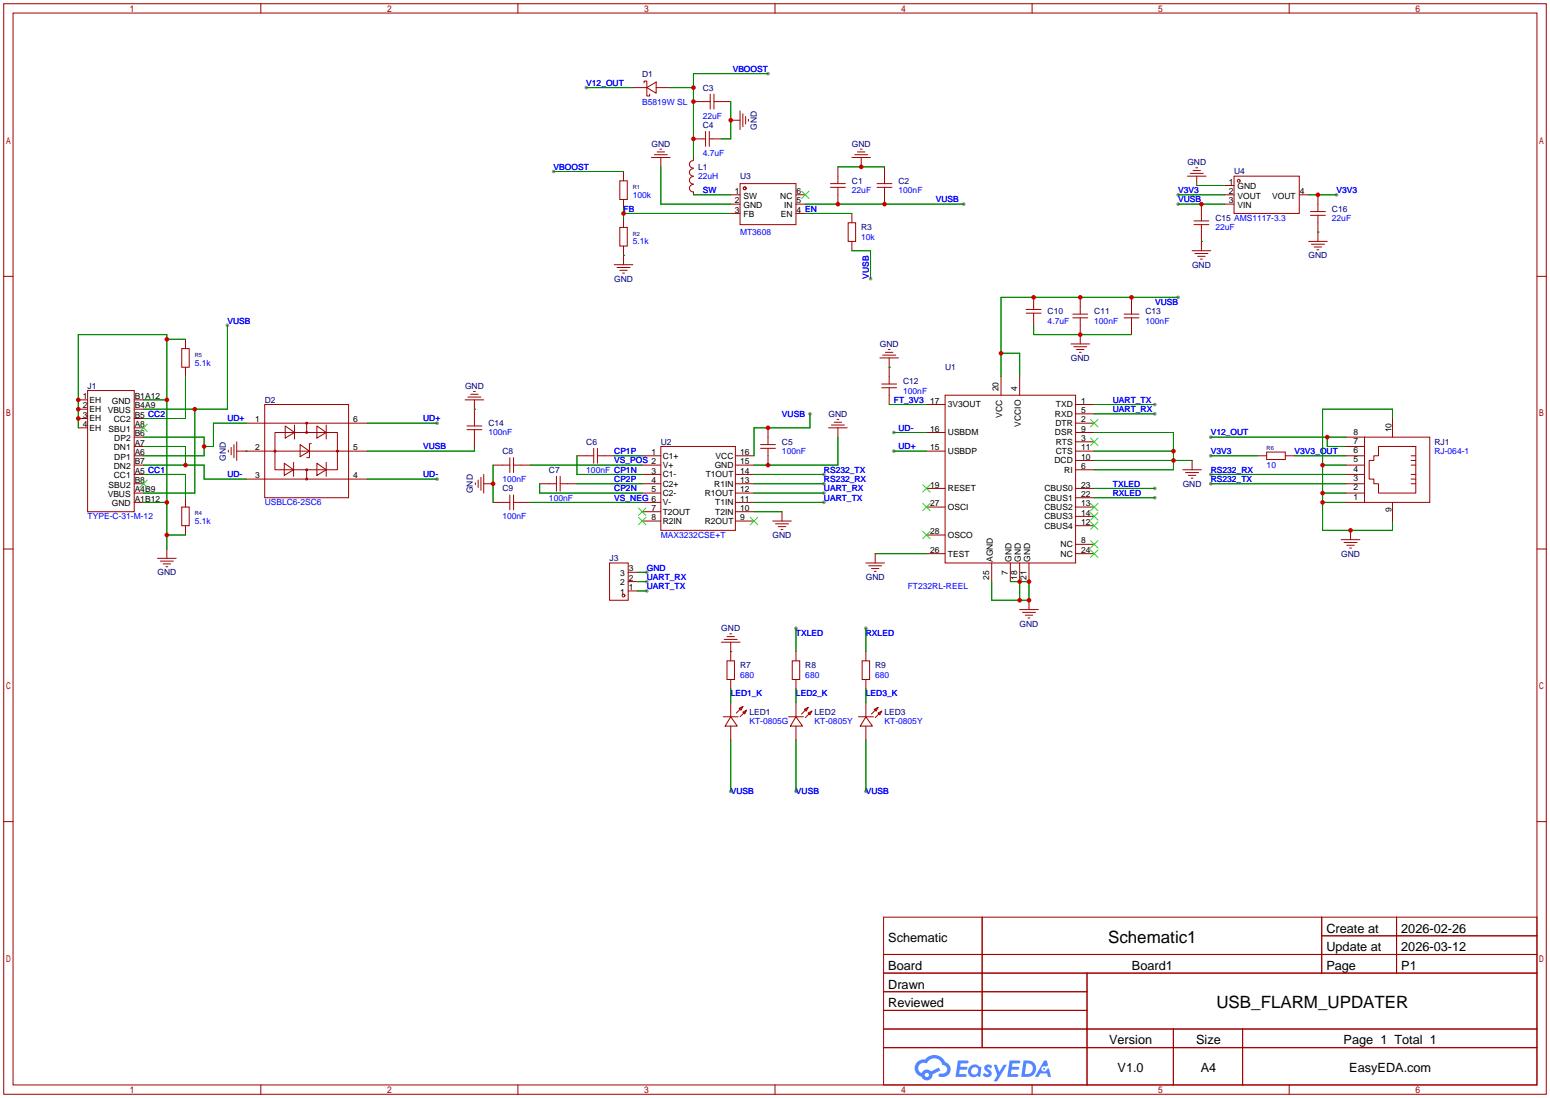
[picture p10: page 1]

Schematic | Schematic1 | Create at | 2026-02-26

Update at | 2026-03-12

Board | Board1 | Page | P1
Drawn | | USB_FLARM_UPDATER
Reviewed

Version | Size | Page 1 Total 1
V1.0 | A4 | EasyEDA.com

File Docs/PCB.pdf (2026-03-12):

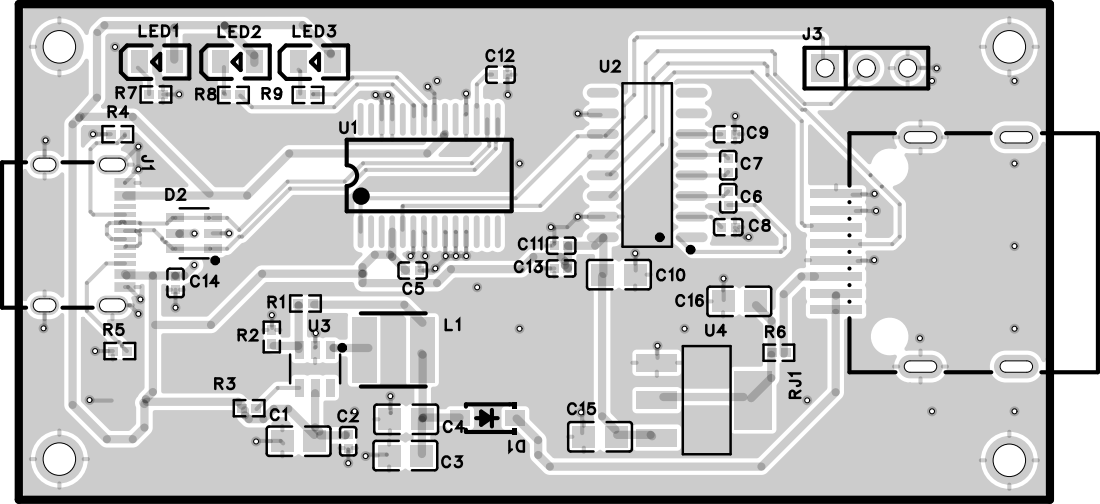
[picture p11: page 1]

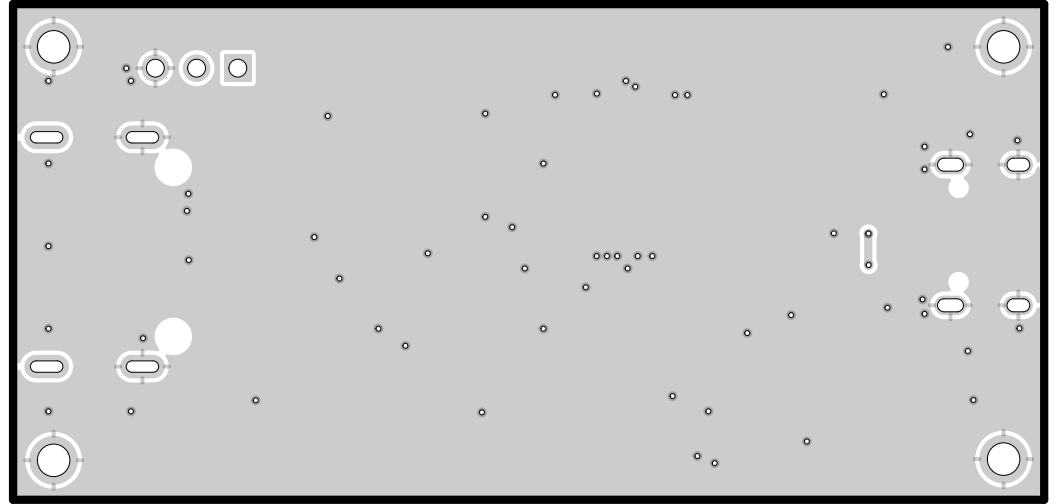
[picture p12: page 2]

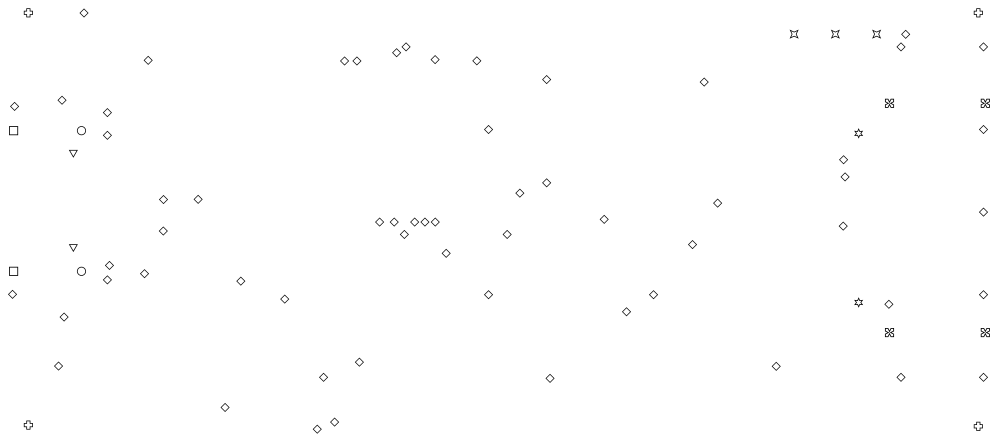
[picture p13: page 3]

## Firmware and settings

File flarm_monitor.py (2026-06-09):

"""Monitor a serial port, log to file with timestamps.

Usage: python flarm_monitor.py [PORT] [BAUD]   (defaults: COM11 19200)
"""
import serial
import time
import sys
from datetime import datetime

PORT = sys.argv[1] if len(sys.argv) > 1 else "COM11"
BAUD = int(sys.argv[2]) if len(sys.argv) > 2 else 19200
LOG_FILE = f"{PORT.lower()}_log.txt"
DURATION_HOURS = 6

def main():
    start = time.time()
    end = start + DURATION_HOURS * 3600

    print(f"Monitoring {PORT} @ {BAUD} baud for {DURATION_HOURS}h")
    print(f"Logging to {LOG_FILE}")
    print(f"Started: {datetime.now().strftime('%Y-%m-%d %H:%M:%S')}")
    print("Press Ctrl+C to stop early.\n")

    try:
        ser = serial.Serial(PORT, BAUD, timeout=1)
    except serial.SerialException as e:
        print(f"Error opening {PORT}: {e}")
        sys.exit(1)

    line_count = 0
    byte_count = 0

    try:
        with open(LOG_FILE, "a", encoding="utf-8", errors="replace") as f:
            f.write(f"\n{'='*60}\n")
            f.write(f"Session start: {datetime.now().isoformat()}\n")
            f.write(f"Port: {PORT} @ {BAUD} baud\n")
            f.write(f"{'='*60}\n")
            f.flush()

            while time.time() < end:
                try:
                    raw = ser.readline()
                except serial.SerialException as e:
                    ts = datetime.now().strftime("%H:%M:%S.%f")[:-3]
                    msg = f"[{ts}] !!! Serial error: {e}\n"
                    f.write(msg)
                    f.flush()
                    print(msg, end="")
                    time.sleep(1)
                    continue

                if raw:
                    ts = datetime.now().strftime("%H:%M:%S.%f")[:-3]
                    try:
                        text = raw.decode("ascii", errors="replace").rstrip("\r\n")
                    except Exception:
                        text = repr(raw)
                    line = f"[{ts}] {text}\n"
                    f.write(line)
                    byte_count += len(raw)
                    line_count += 1
                    if line_count % 100 == 0:
                        f.flush()
                        elapsed = (time.time() - start) / 3600
                        print(f"  {line_count} lines, {byte_count} bytes, {elapsed:.1f}h elapsed")

            f.write(f"\n{'='*60}\n")
            f.write(f"Session end (timeout): {datetime.now().isoformat()}\n")
            f.write(f"Lines: {line_count}, Bytes: {byte_count}\n")
            f.write(f"{'='*60}\n")

    except KeyboardInterrupt:
        with open(LOG_FILE, "a") as f:
            f.write(f"\n{'='*60}\n")
            f.write(f"Session end (user stop): {datetime.now().isoformat()}\n")
            f.write(f"Lines: {line_count}, Bytes: {byte_count}\n")
            f.write(f"{'='*60}\n")
    finally:
        ser.close()

    elapsed = (time.time() - start) / 3600
    print(f"\nDone. {line_count} lines, {byte_count} bytes in {elapsed:.1f}h")
    print(f"Log: {LOG_FILE}")

if __name__ == "__main__":
    main()

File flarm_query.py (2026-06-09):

"""Send a FLARM version query to check if it responds.

Usage: python flarm_query.py [PORT] [BAUD]   (defaults: COM11 19200)
"""
import serial
import sys
import time

PORT = sys.argv[1] if len(sys.argv) > 1 else "COM11"
BAUD = int(sys.argv[2]) if len(sys.argv) > 2 else 19200

def nmea_checksum(sentence):
    """Calculate NMEA checksum for string between $ and *."""
    cs = 0
    for c in sentence:
        cs ^= ord(c)
    return f"{cs:02X}"

def send_nmea(ser, body):
    cs = nmea_checksum(body)
    msg = f"${body}*{cs}\r\n"
    ser.write(msg.encode("ascii"))
    print(f"TX: {msg.strip()}")

ser = serial.Serial(PORT, BAUD, timeout=2)
time.sleep(0.1)

# Flush any stale data
ser.reset_input_buffer()

# Try a few common FLARM queries
queries = [
    "PFLAV,R",      # Version request
    "PFLAC,R,DEVTYPE",  # Device type
    "PFLAC,R,ID",   # Device ID
]

for q in queries:
    send_nmea(ser, q)
    time.sleep(0.5)

    # Read responses for up to 2 seconds
    deadline = time.time() + 2
    while time.time() < deadline:
        line = ser.readline()
        if line:
            print(f"RX: {line.decode('ascii', errors='replace').strip()}")
        else:
            break

print("\nDone. (Run flarm_monitor.py to log the full stream to a file.)")
ser.close()

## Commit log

2026-02-25 Initial commit – FLARM USB Updater hardware project
    USB-to-RS232 adapter with MT3608 5V→12V boost converter for
    updating FLARM firmware without external 12V supply. Uses FT232RL
    (FTDI), MAX3232 RS232 transceiver, USB-C input, RJ45 FLARM output.
    EasyEDA Pro / JLCPCB design.
2026-02-26 Add finalized BOM, pinout, and schematic drawing guide
    - README: complete BOM with all JLCPCB C-numbers, FLARM RJ45 pinout,
    LED table, boost formula, cost estimate
    - Docs/schematic-drawing-guide.md: step-by-step EasyEDA Pro guide
    covering block placement, component placement, all wiring connections,
    ERC checklist, and export instructions
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2026-02-26 Replace C1525 with C307331 (Samsung 100nF 0402) — fixes EasyEDA footprint error
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2026-02-27 Add PCB layout guide and EDA project files
    - Add Docs/pcb-layout-guide.md and .html: full EasyEDA Pro PCB layout
    guide with routing rules, component placement, and JLCPCB requirements
    - Add EDA/ directory with EasyEDA Pro project and netlist export
    - Update README with PCB dimensions, layout notes, and critical schematic
    verification items (FT232RL TEST pin, CTS#/DSR#/DCD# grounding)
    - Update schematic drawing guide with latest corrections
2026-02-27 Convert trace widths from mm to mils throughout PCB guides
    Use EasyEDA-native units: 10mil standard signal traces, 5mil steps for
    power (15mil V12_OUT, 20mil VUSB/VBOOST/SW). Update both .md and .html
    versions of the PCB layout guide and README routing requirements section.
2026-02-27 Add extracted PCB/schematic JSON and updated EDA project
    - EDA/extracted/pcb_decoded.json — decoded PCB layout data (58KB)
    - EDA/extracted/schematic_decoded.json — decoded schematic data (42KB)
    - Updated .eprj project file (v63 backup included)
2026-02-27 Add comprehensive design review and improvement guide
    Full review of pcb_decoded.json and schematic_decoded.json covering:
    - Verified all FT232RL critical pins (TEST, CTS#, DSR#, DCD#, RI#) → GND
    - USB D+/D- analysis: path match 0.001mm, vias acceptable for Full Speed
    - Power budget at 300mA FLARM: L1 inductor at 93% saturation (upgrade needed)
    - MT3608 switch current OK (0.93A vs 2A max), but L1 is the bottleneck
    - USB draw ~910mA requires USB-C 1.5A+ source, not laptop USB 2.0
    - Confirmed D1 Schottky provides reverse protection on V12_OUT
    - Confirmed R7 (10Ω) correct as 3.3V balancing resistor
    - Net name cleanup recommendations for 15 auto-generated nets
    - Specific upgrade paths: L1 to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
2026-02-27 Add comprehensive power analysis — USB can power FLARM for updates
    Research shows the 300mA@12V assumption was overly conservative.
    Real FLARM power consumption: 95-165mA@12V (model dependent).
    During firmware updates (bootloader mode): ~80mA@12V = only 280mA
    from USB — works on any USB port including USB 2.0.
    Full analysis of 6 design options with trade-offs. Recommendation:
    keep 12V output, upgrade L1 inductor, update documentation.
    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
2026-02-27 Add boost converter alternatives, USB-C power options, PCB improvements
    - MT3608 clones (SDB628, SX1308) offer no efficiency gain
    - TPS61088 synchronous boost is the real upgrade (90-93% vs 85-88%)
    but requires QFN-20 footprint — v2 candidate
    - STUSB4500 autonomous USB PD sink can negotiate 12V directly
    eliminating boost converter losses — v2 candidate
    - USB BC 1.2 DCP not applicable (needs D+/D- for serial data)
    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
2026-03-08 Add AMS1117-3.3 LDO, breakout headers, and expanded documentation
    - Replace FT232RL 3V3OUT with dedicated AMS1117-3.3 LDO (U4, 800mA) for
    RJ45 pin 3 display power, adding C15/C16 bulk caps
    - Add breakout headers: J3 (MAX3232 channel 2, 1×4) and J4 (TTL UART, 1×3)
    as unpopulated through-hole headers for optional hand-soldering
    - Document additional use cases: IGC download, FLARM config, NMEA diagnostics,
    general-purpose RS232 adapter
    - Add cable configurations (straight/crossover/RS232-only)
    - Add FT232RL EEPROM customization notes (FT_PROG)
    - Add PCB layout sections: mounting holes, test points, silkscreen, headers
    - Update BOM to 35 components (still 7 Extended, $21 setup fees)
    Co-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
2026-03-09 PCB layout and routing — initial 2-layer placement and routing
    - Component placement: signal zone (top), power zone (bottom)
    - Routed all nets including boost loop, USB D+/D-, UART, RS232
    - Added GND copper pour on bottom layer
    - Updated docs to reflect layout decisions
    - Added EasyEDA project backups and autorouter exports
    [Autorouter_PCB1_2026-3-9.dsn]
2026-03-11 Update schematic/PCB, add analysis docs and exports
    - Updated EasyEDA project with LED component changes, RJ1 rename, R8/R9/R10 rework
    - Added eprj analysis document with LED polarity verification checklist
    - Added PCB netlist, schematic PDF, PCB layout PDF, 3D STEP model
    - Added Altium export and KiCad backup (v132, v133)
    - Fixed README: breakout header section (J3 only), component count (37)
    - Updated pcb-layout-guide with latest routing details
    [1_P1.schdoc, 3D_PCB2_2026-03-10.step, PCB1.pcbdoc]
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2026-03-11 Update schematic, remove old Altium export
    [1_P1.schdoc, PCB1.pcbdoc]
2026-03-12 Fix LED polarity, resistor footprints, and SMD RJ45 connector
    - Fix LED1/2/3 orientation: all anodes (pad1) now connect to VUSB
    - Change R7/R8/R9 from 0603WAF4700T5E to 0402WGF4700TCE (C25117, Basic)
    - LED footprint standardized to led0805-r-rd for correct JLCPCB placement
    - RJ1 changed to SMD RJ45 (conn-smd_rj-064) with correct pin mapping
    - README BOM updated: R6=10Ω (LDO), R7/R8/R9=470Ω 0402
    - Verified all connections against FLARM IGC spec
    - Backup of pre-edit eprj included
2026-03-12 Clean up project for publishing: add datasheets, design doc, update schematic
    - Add 10 component datasheets (FT232RL, MAX3232, MT3608, AMS1117, etc.)
    - Add DOCX design document for lead engineer review
    - Add updated schematic PDF, PCB PDF, and 3D STEP model
    - Update EasyEDA project: 680Ω LED resistors, fixed LED footprints, net names
    - Remove old backups, working docs, autorouter files, KiCad exports
    - Update .gitignore for EasyEDA artifacts and Node.js files
    [3D_PCB1_2026-03-12.step, 3D_PCB2_2026-03-10.step, Autorouter_PCB1_2026-3-9.dsn]
2026-03-14 REV A: shrink PCB to 53.4x30.5mm, update all docs, add Gerber/BOM
    - PCB shrunk from 63.5mm to 53.4mm length (16% smaller)
    - README rewritten for REV A: correct BOM (680Ω LEDs, LED2=green),
    net names table, power budget, boost specs, design verification
    - Design doc regenerated with REV A designation and board dimensions
    - EasyEDA project updated with compact layout and routing
    - Added Gerber and BOM exports for JLCPCB
    [3D_PCB1_2026-03-12.step, BOM_Board1_PCB1_2026-03-14.xlsx]
2026-03-16 Fix LED2 colour in docs: Green -> Yellow (KT-0805Y / C2296)
    Schematic was correct; README had LED2 listed as Green (C2297/KT-0805G)
    instead of Yellow (C2296/KT-0805Y). Fixed in both the component table
    and the LED indicators table.
2026-04-04 REV A tested: add errata, rework guide, updated EDA/BOM, 6h soak test log
    - README: add MT3608 errata (E1: boost topology wrong, E2: VCCIO 5V)
    - Add REV A rework guide (md, html, pdf) and rework PDF generator
    - Update EDA project to REV C schematic, replace old BOM/Gerber/STEP
    - Add 6-hour COM11 soak test log (114k lines, 0 errors) and test scripts
    - Add 1:1 PCB print helper
    [3D_PCB1_2026-03-12.step, BOM_Board1_PCB1_2026-03-14.xlsx, BOM_Board1_PCB1_2026-03-17.xlsx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]
2026-04-20 REV B: fix +12V rail (REV A boost bug), archive REV A, update all docs
    REV B corrects the REV A boost converter topology that left the 12V rail at
    0V on every first-run board. L1 now sits between VUSB and SW, and D1 between
    SW and V12_OUT -- the textbook boost path. R3/C2/C4 removed (not required by
    MT3608 datasheet). VCCIO is intentionally left on VUSB (5V) in this revision;
    moving it to FT_3V3 is deferred to a future board.
    - Fab outputs for 2026-04-20 added under EDA/ (BOM, Gerber, Netlist)
    - REV A schematic, PCB, BOM, Gerber, PnP, rework guide and com11 soak log
    moved to Archive/REV_A/ (via git mv, history preserved)
    - README.md rewritten as the REV B shipping document; REV A errata s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
    [BOM_Board1_PCB1_2026-03-17.xlsx, BOM_Board1_PCB1_2026-04-20.csv, PickAndPlace_PCB1_2026-03-17.xlsx]
2026-04-23 Format README.md tables (markdown lint)
    Column-align the BOM, nets, and RJ45 pinout tables. No content changes.
2026-05-17 Docs: correct MAX3232 supply + VCCIO/J3 logic level
    MAX3232 VCC + bypass C5 moved from VUSB (5V) to the 3.3V rail (AMS1117
    V3V3) to close a worst-case out-of-spec logic-high margin against the
    FT232RL TXD at VCCIO=3.3V. Correct the long-standing doc error that
    claimed VCCIO was tied to 5V (it is on 3V3OUT): J3 is 3.3V TTL and safe
    for 3.3V MCUs. Drop stale dated Gerber/BOM/netlist references.
2026-05-17 REV B 2026-05-17: audited boost + MAX3232 fix, fresh fab exports
    Schematic + PCB + exported-netlist all cross-verified: boost topology
    correct (VUSB->L1->SW; D1 anode@SW cathode@V12_OUT; R1 100k/R2 5.1k ->
    12.36V), MAX3232 on 3.3V rail, USB diff pairs matched, FB trace tidy.
    Adds 2026-05-17 Gerber/BOM/netlist/P&P and regenerated design doc.
    Fix create_design_doc.js: write relative to __dirname (was a stale
    hardcoded absolute path that broke regeneration).
    [BOM_Board1_PCB1_2026-05-17.csv, PickAndPlace_PCB1_2026-05-17.xlsx]
2026-05-17 Remove stale 2026-04-20 fab artifacts superseded by 2026-05-17
    The 2026-04-20 Gerber/BOM/netlist predate the boost + MAX3232 fixes;
    the 2026-05-17 set is the authoritative fab output. REV A history is
    preserved separately in Archive/REV_A/.
    [BOM_Board1_PCB1_2026-04-20.csv]
2026-05-17 Add CERN-OHL-S v2 LICENSE and README license section
    Licenses the open-hardware design under CERN-OHL-S-2.0 (strongly
    reciprocal) so derivative boards must stay open. Clarifies FLARM/
    PowerFLARM trademarks are excluded from the licence.
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2026-05-17 REV B: add back-silkscreen artwork (logo, licence, trademark) + re-export Gerber
    Bottom silkscreen now carries the RVdB.dev mark, full project name,
    rev/date, CERN-OHL-S v2 licence notice and FLARM trademark disclaimer.
    Gerber re-exported so fab files include the new artwork.
2026-05-26 REV B: pre-fab audit (schematic + PCB layout, 0 wiring violations)
    May-20 source file added. Audited with vendored pcb-schematic-audit skill:
    all 24 named nets and component pin assignments verified against
    datasheets (FT232RL, MAX3232, MT3608, AMS1117, USBLC6, B5819W).
    USB diff pairs perfectly length-matched (Δ<0.1 mil). Two pre-fab
    blockers identified: existing Gerber/BOM/PnP/netlist exports are from
    May-17 and predate the back-silkscreen artwork commit; LED2/LED3 and
    J3 part numbers swapped between May-17 BOM and May-20 source.
2026-05-26 REV B fab-ready: clean re-export 2026-05-27, BOM-aware audit script
    EDA: replace dated source + fab artifacts with a fresh export from the
    EasyEDA Pro cloud project. ProPrj source dated 2026-05-26; Gerber, BOM,
    Pick-and-Place and netlist exported 2026-05-27. Two earlier dated .epro
    files (2026-05-17 and 2026-05-20) and their stale fab outputs are dropped
    in favour of the single 2026-05-26 source.
    Audit verdict (.audit_skill/scripts/esch_parser.py + pcb_audit.py):
    - 0 wiring violations
    - All 29 named nets verified against datasheets
    - FT_3V3 carries VCCIO (pin 4) + 3V3OUT (pin 17) with C12 decoupling
    - MAX3232 VCC on V3V3 (3.3V rail) — both ICs share the FT232 logic level
    - USB diff pairs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
    [BOM_Board1_PCB1_2026-05-27.csv, PickAndPlace_PCB1_2026-05-17.xlsx, PickAndPlace_PCB1_2026-05-27.xlsx]
2026-05-27 Public-repo prep: sponsor links, branding assets, settings hygiene
    Adds .github/FUNDING.yml with Buy Me a Coffee (buymeacoffee.com/rikvdb)
    so GitHub shows a Sponsor button at the top of the repo. README gains a
    "Support the project" section explaining the open-hardware deal: design
    is free to copy/build from EDA/, a coffee or a pre-built board funds the
    next iteration.
    Branding: vectorises the RVdB.dev logo from the bottom silkscreen into a
    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
2026-06-08 REV B validated: enclosure, board photos, audit board-profiles
    Bring-up confirmed REV B works end-to-end (boost powers a real FLARM,
    full bidirectional serial). Repo updates following physical validation:
    - Enclosure/: 3D-printable case (box + lid as STEP/3MF/STL) plus
    enclosure-assembly.step (board-in-box fit reference, do not print)
    - Images/: cleaned board photos (top / in-use / back), oriented,
    cropped, compressed; wired into README (hero, usage, pinout)
    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
    [3DPCB.step, FLARM_USB_UPDATER.step, box.3mf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]
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2026-06-08 Prep public cleanup: drop bundled datasheets link, ignore internal paths
    - README: component datasheets now referenced via LCSC codes in the BOM
    instead of bundling third-party copyrighted PDFs
    - .gitignore: exclude .claude/, .audit_skill/, Datasheets/, *_log.txt
    (History rewrite in the next step purges these paths + the REV A serial
    log, which contained GPS fixes, from all history.)
2026-06-09 Tidy repo: clearer script names, drop doc generator
    - poke_flarm.py -> flarm_query.py (query FLARM version/device info)
    - monitor_com11.py -> flarm_monitor.py (log serial NMEA stream; old name
    implied COM11, which it no longer requires)
    - update in-script usage strings + README references
    - remove Docs/create_design_doc.js (personal doc-build helper); the
    generated design document .docx stays
    [flarm_monitor.py, flarm_query.py]
2026-06-09 README: note harmless COM-port blip when hot-plugging the FLARM
    Hot-plugging the FLARM charges its input caps through the boost, which
    spikes the 5V USB rail and momentarily brown-outs / re-enumerates the
    FT232. Document it as expected behavior + give the connection-order tip.
2026-06-09 README: add contact routing (Issues=bugs, Discussions, flarm@rvdb.dev)
    Route contact cleanly now that Discussions is enabled and the domain
    address is verified: bugs -> Issues, questions/build help/buy-interest ->
    Discussions, private -> flarm@rvdb.dev. Pre-built-board line no longer
    points buyers at the bug tracker.
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2026-06-11 Enclosure: add clean + branded lid variants, update box
    - lid.* stays the plain lid (no markings) - the default for builders
    - lid_branded.* = same lid with RVdB.dev / USB FLARM UPDATER embossed
    - box.* updated (one wall extruded on the lower-right; lid rim unchanged
    so both lids still fit)
    - README documents the two lid options
    - gitignore the local-only lid emboss artwork SVGs
    [box.3mf, box.step, box.stl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]
